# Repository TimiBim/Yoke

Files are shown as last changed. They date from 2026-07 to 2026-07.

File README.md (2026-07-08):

# Yoke



A sim racing steering wheel / yoke controller built around an STM32G491VE.

## Overview

Yoke is a wheel-side controller for a sim racing rig. It handles button and
encoder input, drives a color touch display, and communicates with the base
over CAN bus. Power and data arrive over a single hot-pluggable connector.

## Features

- **STM32G491VE** (LQFP100, Cortex-M4F @ 170 MHz)
- **FDCAN** link to the wheel base via TCAN332G transceiver
- **ILI9341** 320×240 SPI touch display
- **MCP23017** I²C expander for button matrix
- **Hot-plug safe** — MIC2544 current-limit controller and charge pump so the
  wheel can be connected while the rig is powered
- **ESD protection** on all external connections (ESD2CAN24DCKRQ1)
- **USB-C** for firmware flashing and debug

## Power Architecture

The base supplies a 5 V intermediate rail. An AP2114H-3.3 LDO generates the
local 3.3 V rail on the wheel, keeping the connector current low and avoiding
drop across the cable.

## License

- Hardware: CERN-OHL-S v2
- Firmware: MIT

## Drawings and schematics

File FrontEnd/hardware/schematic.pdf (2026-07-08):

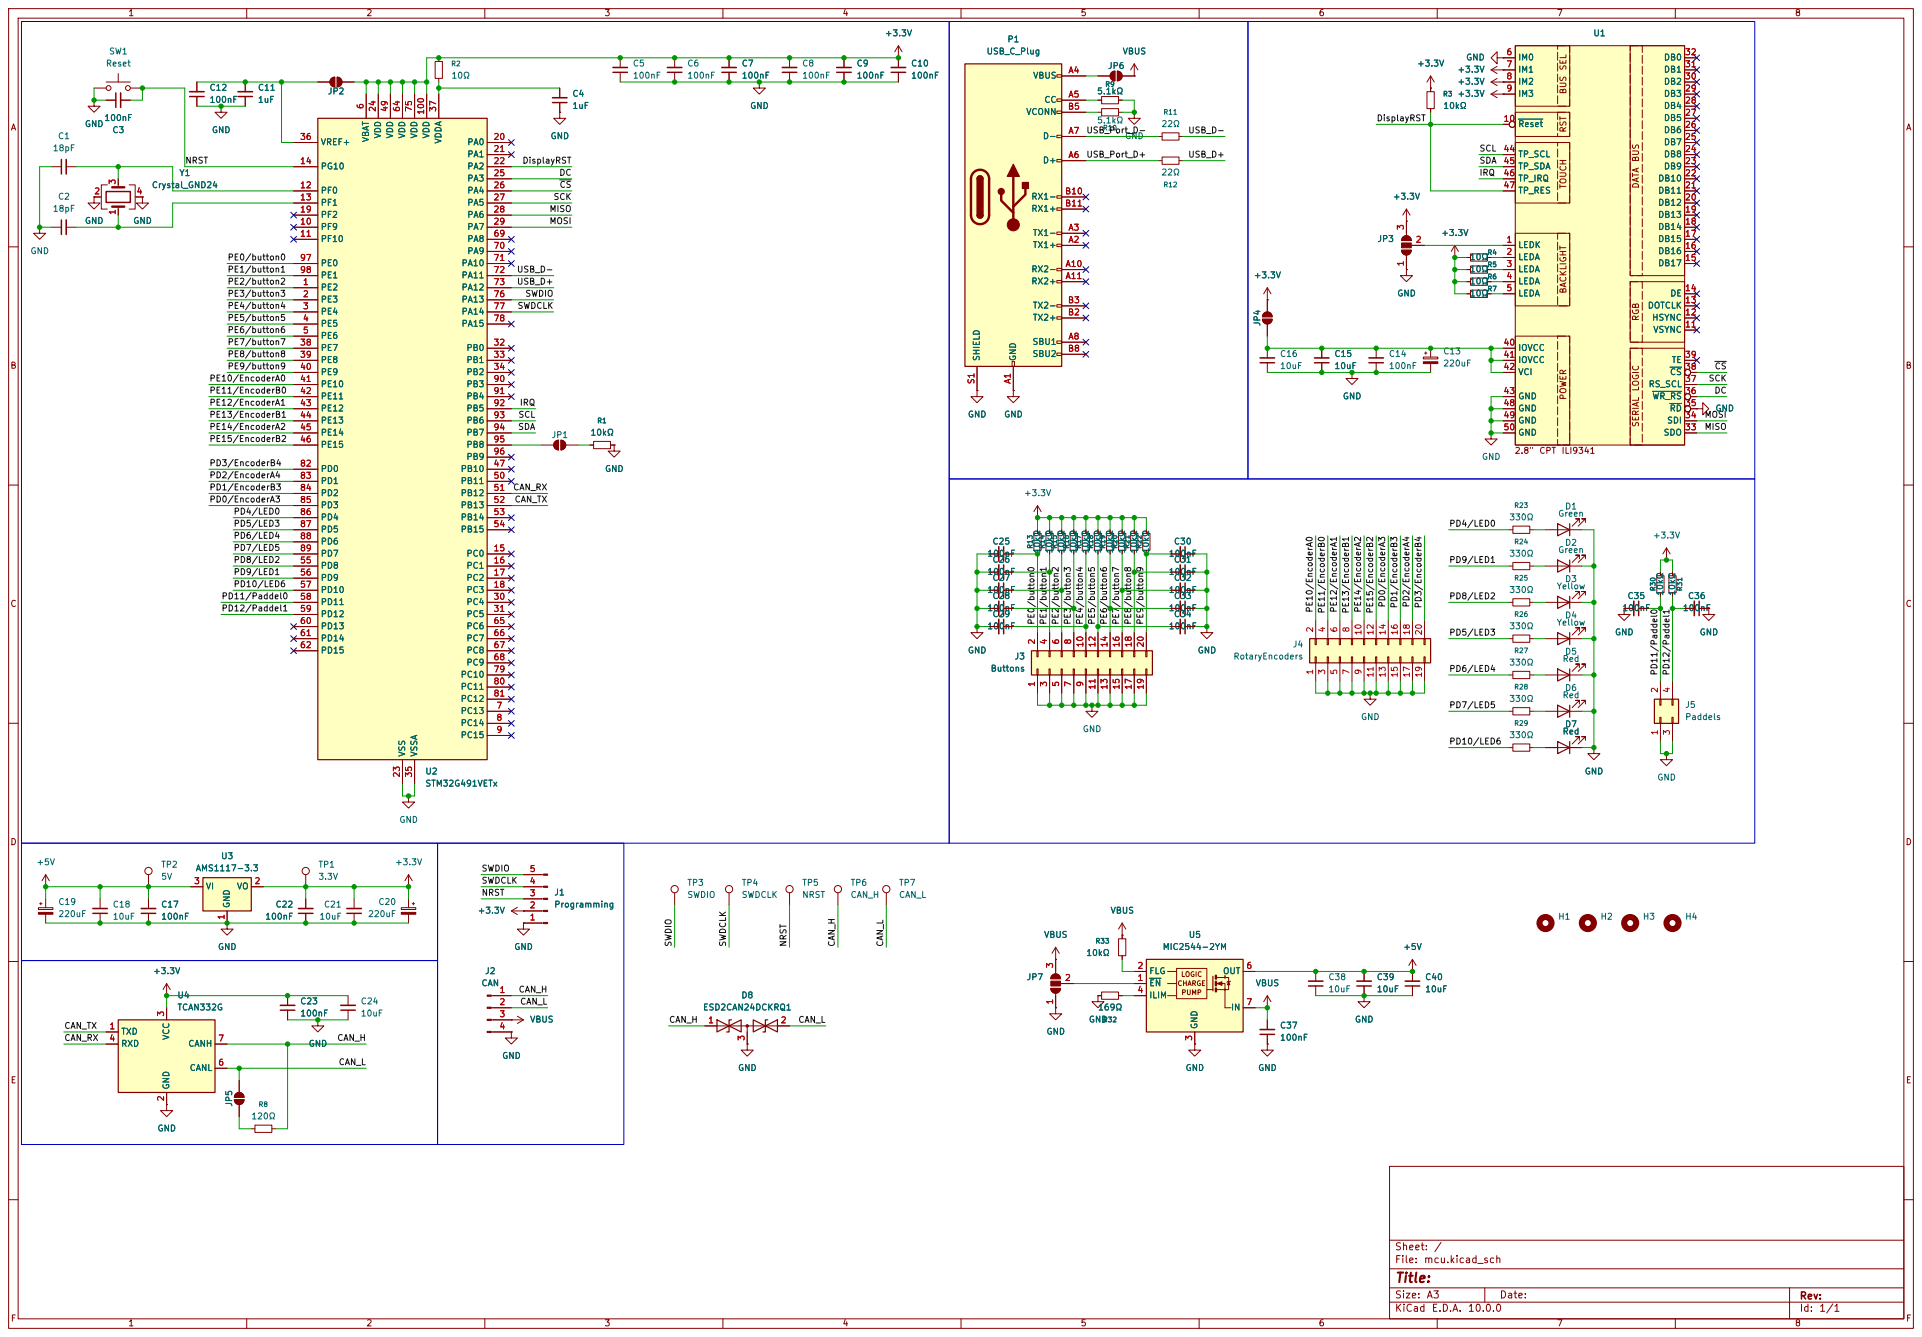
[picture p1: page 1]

VBUS | U1

MISO MOSI DisplayRST DC

LEDK 1

R4 10Ω | LEDA 3

3 RXD 4 CANL 6 CANH 7 JP5 GND

Size: A3 | Rev: | F Date:
KiCad E.D.A. 10.0.0 | Id: 1/1

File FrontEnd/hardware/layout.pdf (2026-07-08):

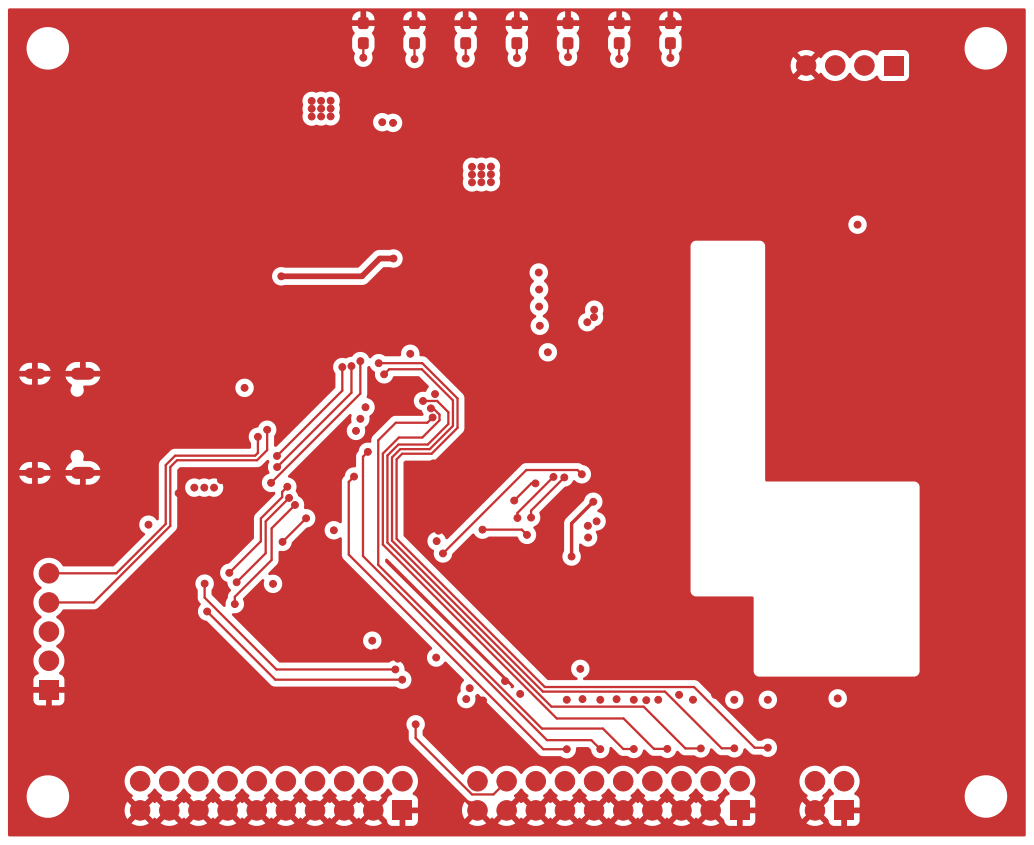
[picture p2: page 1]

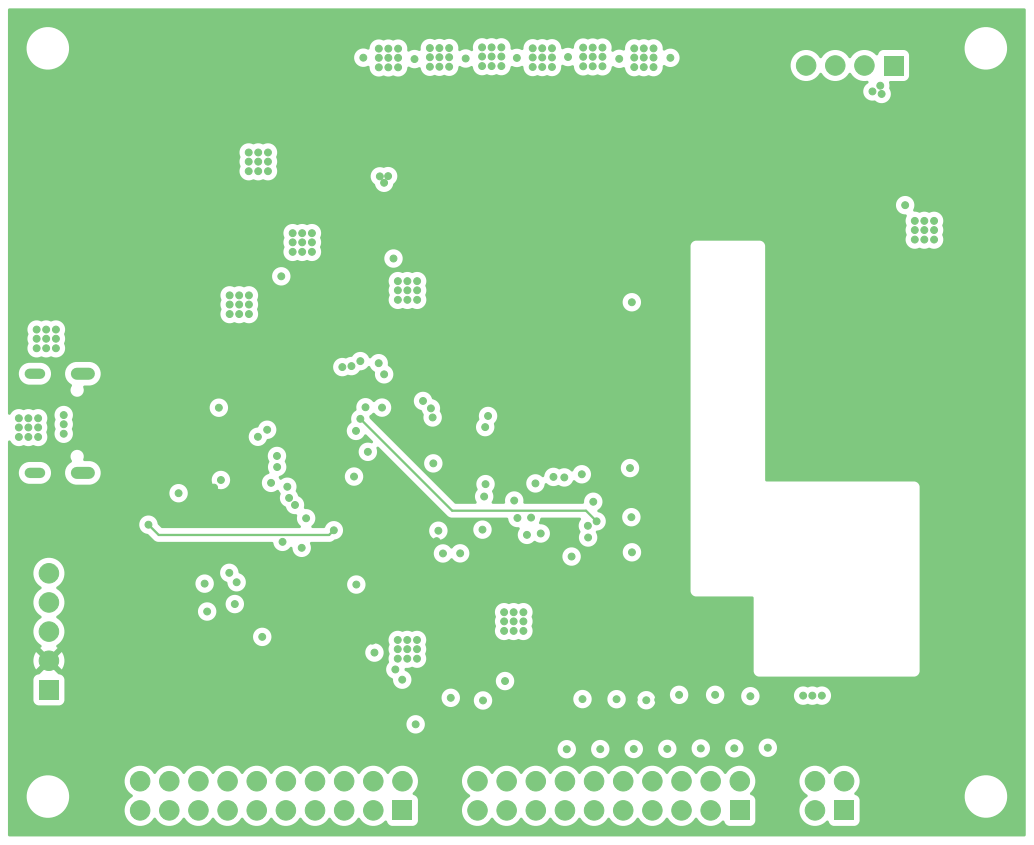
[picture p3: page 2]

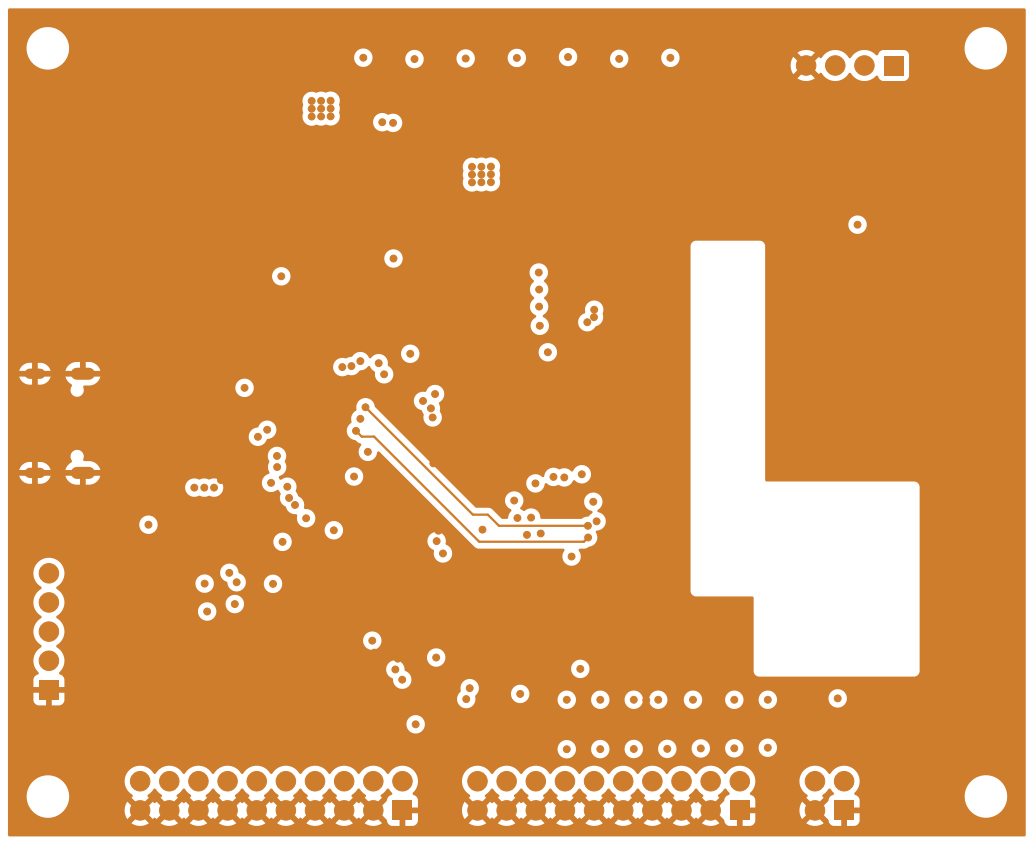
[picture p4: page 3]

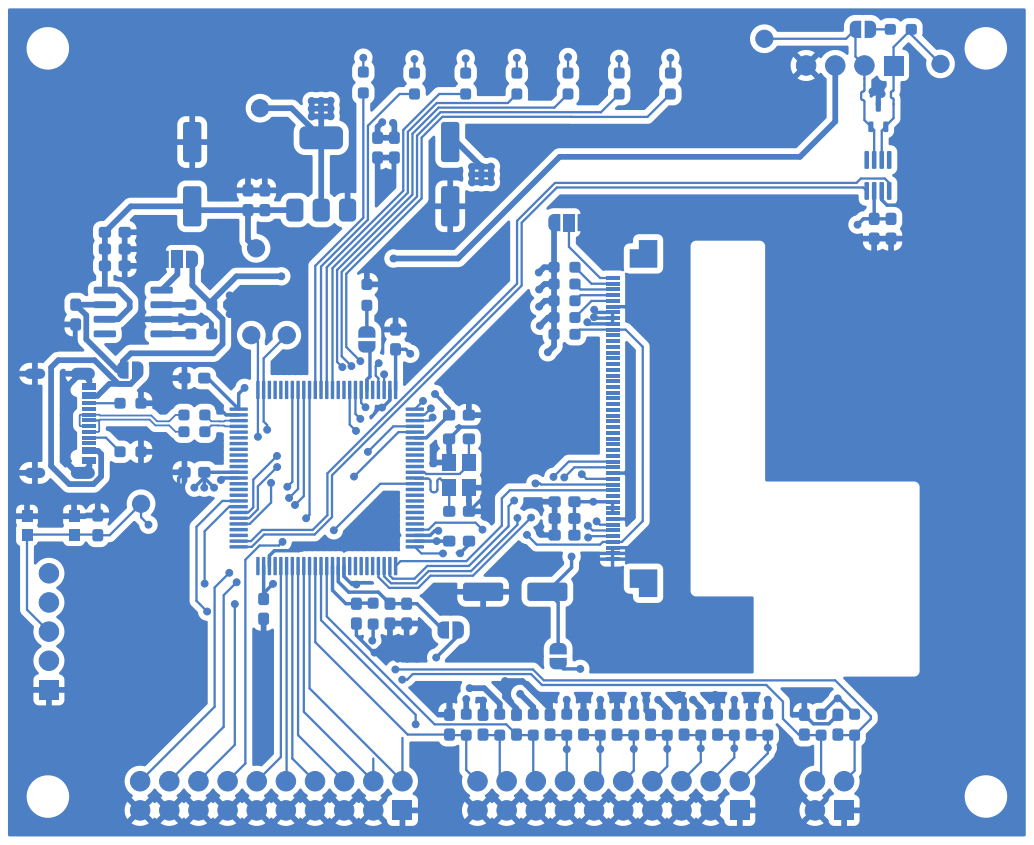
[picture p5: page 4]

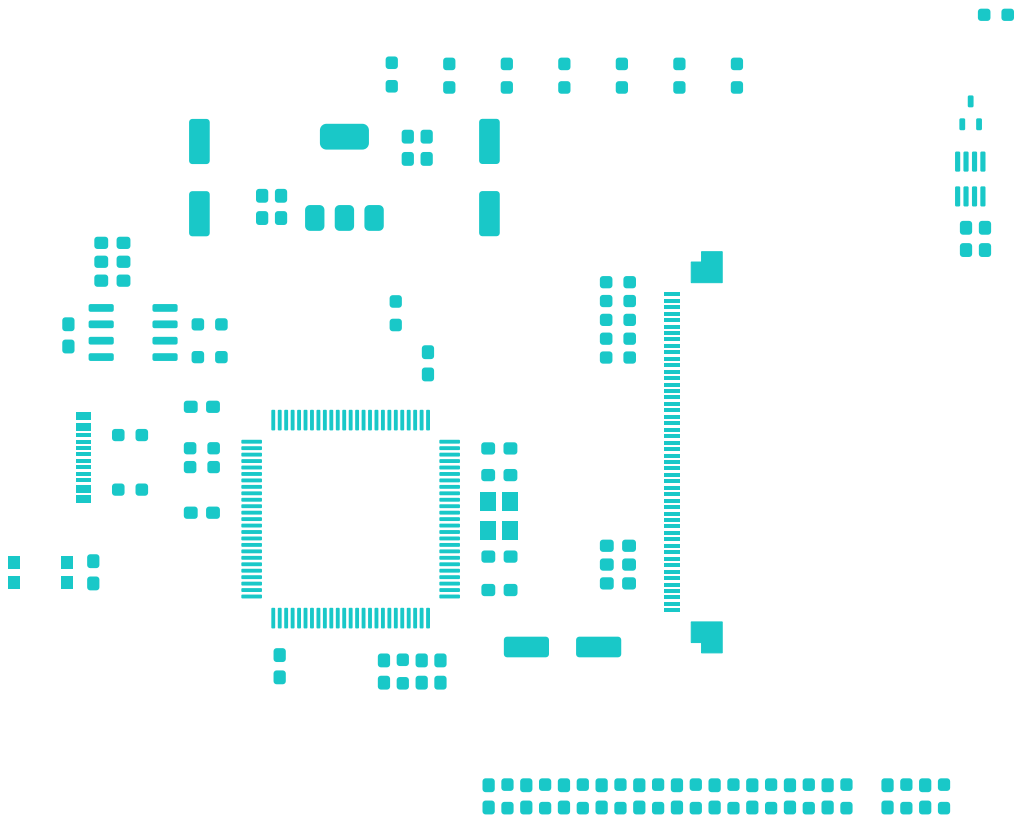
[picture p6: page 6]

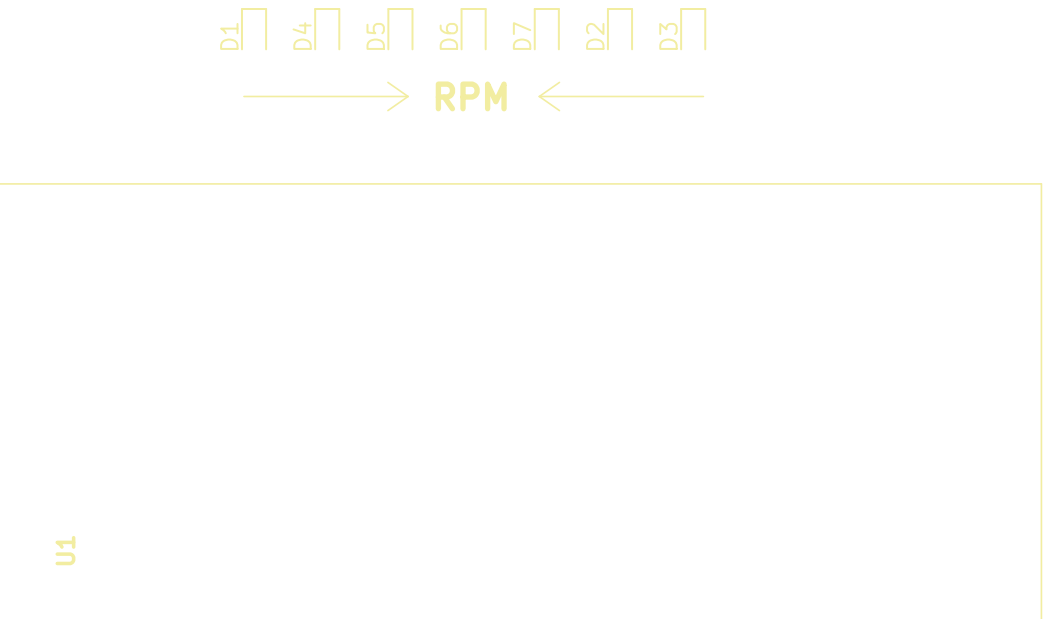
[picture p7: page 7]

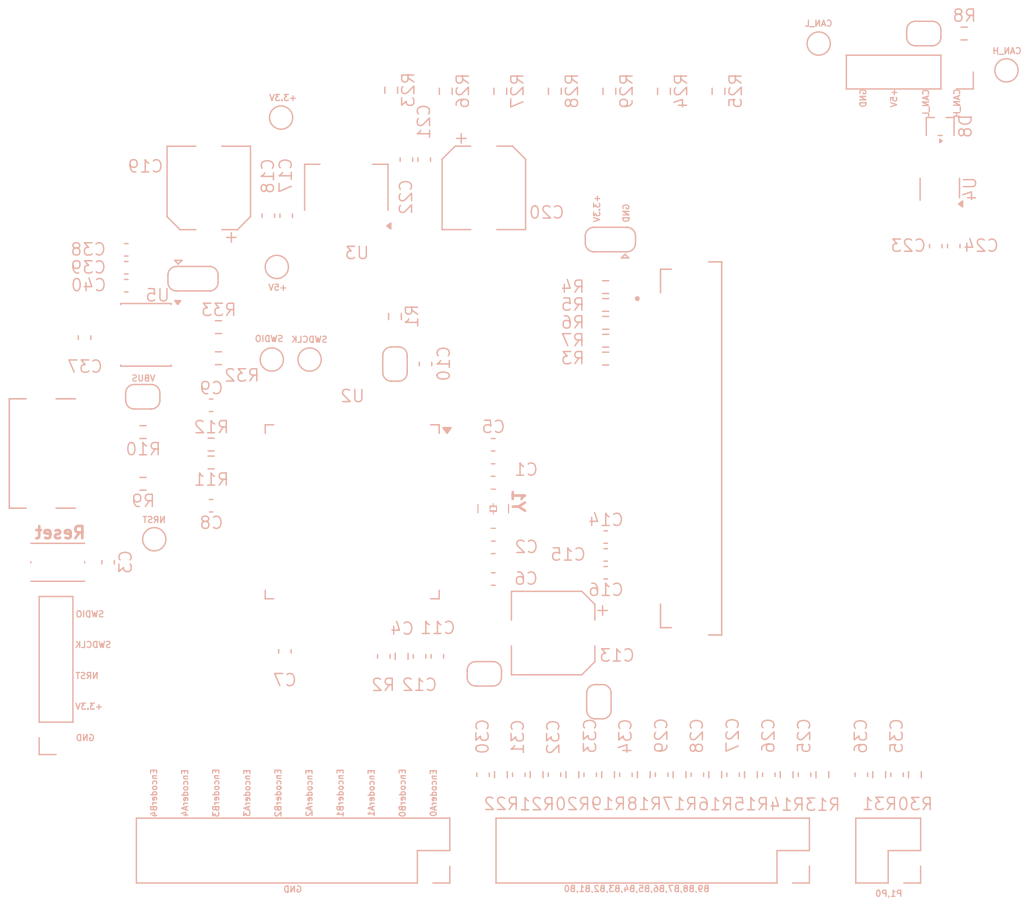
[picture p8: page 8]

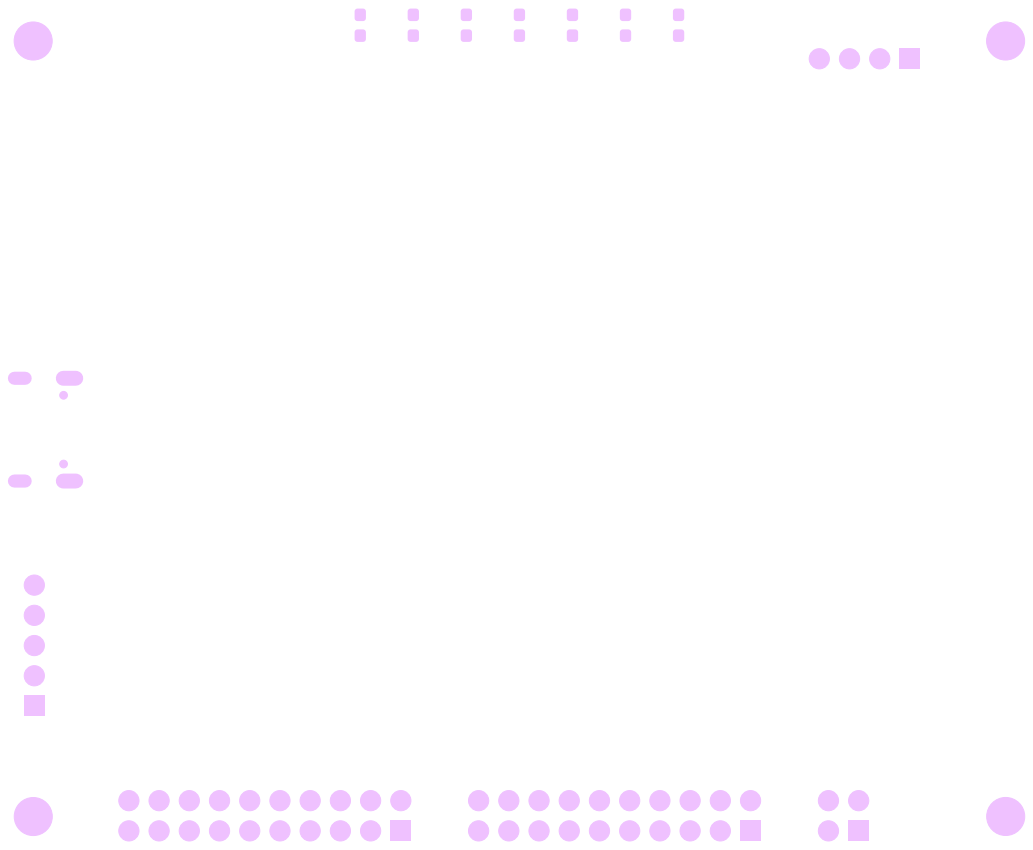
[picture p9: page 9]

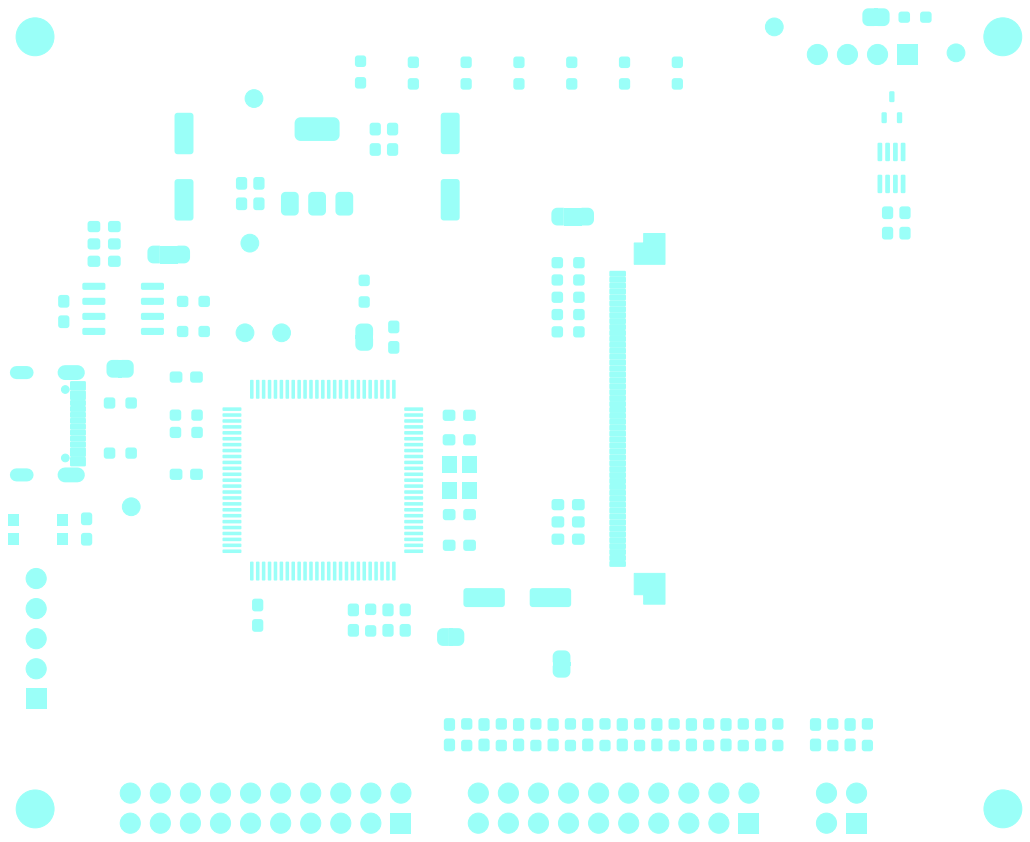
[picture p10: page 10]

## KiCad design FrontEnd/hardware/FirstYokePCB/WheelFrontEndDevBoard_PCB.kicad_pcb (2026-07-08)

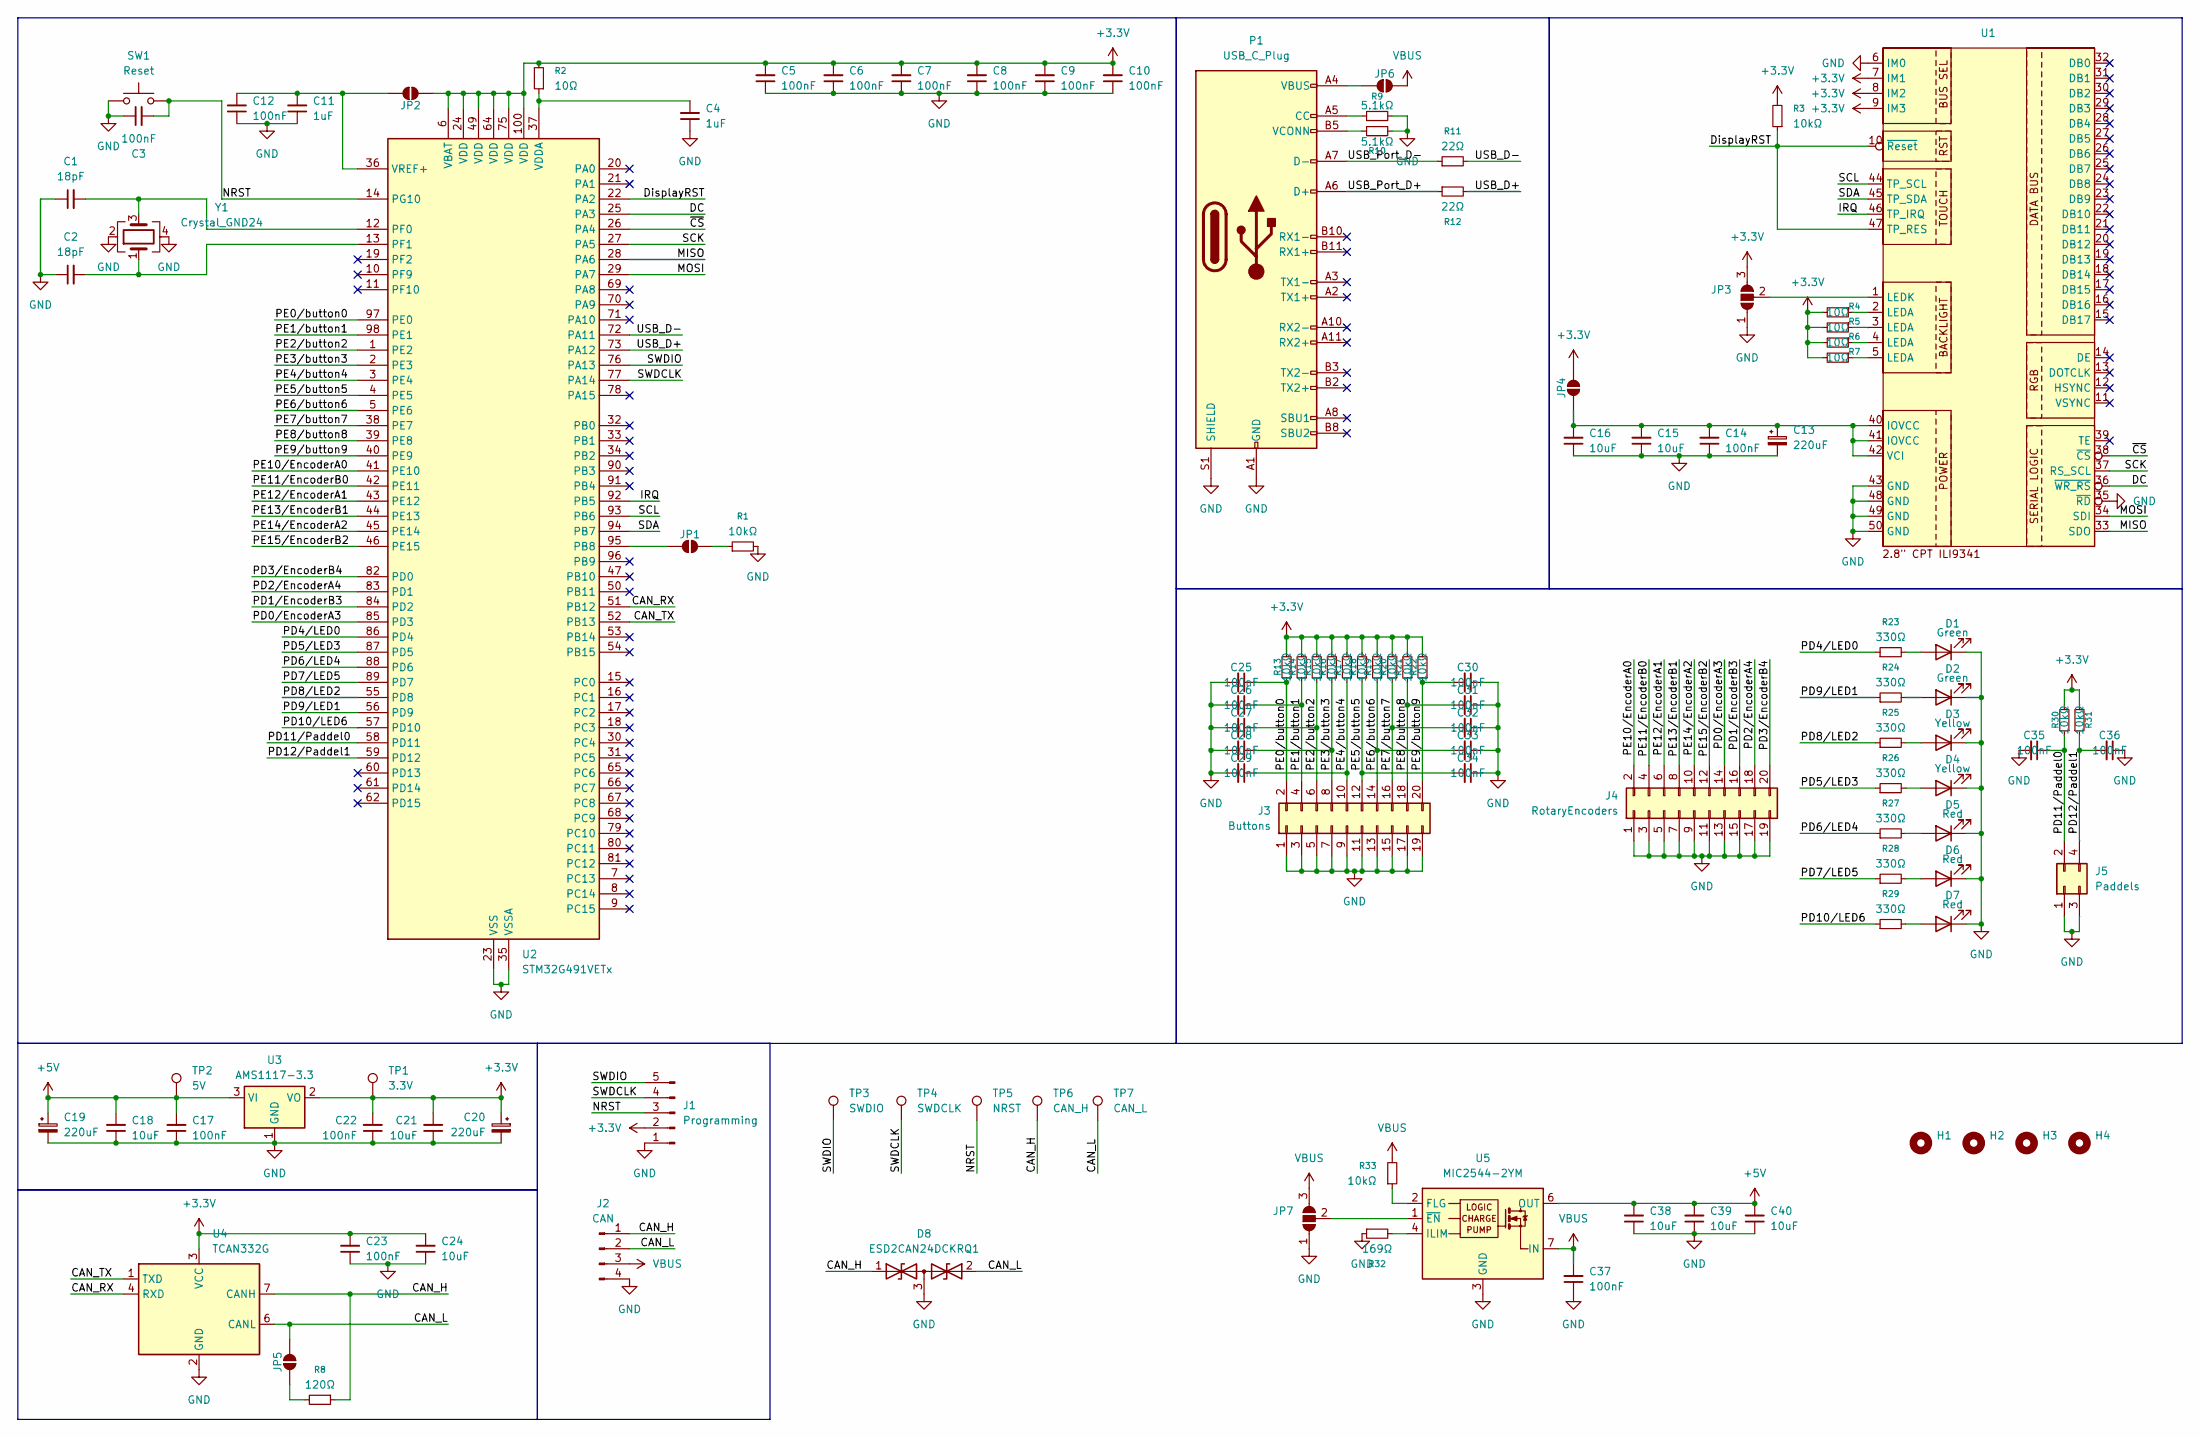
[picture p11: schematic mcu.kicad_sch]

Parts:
C1, C2: 18pF; C_0603_1608Metric_Pad1.08x0.95mm_HandSolder
C3, C5, C6, C7, C8, C9, C10, C12, C14, C17, C22, C23, C25, C26, C27, C28, C29, C30, C31, C32, C33, C34, C35, C36, C37: 100nF; C_0603_1608Metric_Pad1.08x0.95mm_HandSolder
C4, C11: 1uF; C_0603_1608Metric_Pad1.08x0.95mm_HandSolder
C13, C19, C20: 220uF; CP_Elec_6.3x5.3
C15, C16, C18, C21, C24, C38, C39, C40: 10uF; C_0603_1608Metric_Pad1.08x0.95mm_HandSolder
D1, D2: Green; LED_0603_1608Metric_Pad1.05x0.95mm_HandSolder
D3, D4: Yellow; LED_0603_1608Metric_Pad1.05x0.95mm_HandSolder
D5, D6, D7: Red; LED_0603_1608Metric_Pad1.05x0.95mm_HandSolder
D8: ESD2CAN24DCKRQ1; SOT-323_SC-70
H1, H2, H3, H4: MountingHole; MountingHole_3.2mm_M3
J1: Programming; PinHeader_1x05_P2.54mm_Vertical
J2: CAN; PinHeader_1x04_P2.54mm_Vertical
J3: Buttons; PinHeader_2x10_P2.54mm_Vertical
J4: RotaryEncoders; PinHeader_2x10_P2.54mm_Vertical
J5: Paddels; PinHeader_2x02_P2.54mm_Vertical
JP1, JP2, JP4, JP5, JP6: SolderJumper_2_Open; SolderJumper-2_P1.3mm_Open_RoundedPad1.0x1.5mm
JP3, JP7: SolderJumper_3_Open; SolderJumper-3_P1.3mm_Open_RoundedPad1.0x1.5mm
P1: USB_C_Plug; USB-C
R1, R3, R13, R14, R15, R16, R17, R18, R19, R20, R21, R22, R30, R31, R33: 10kΩ; R_0603_1608Metric_Pad0.98x0.95mm_HandSolder
R2, R4, R5, R6, R7: 10Ω; R_0603_1608Metric_Pad0.98x0.95mm_HandSolder
R8: 120Ω; R_0603_1608Metric_Pad0.98x0.95mm_HandSolder
R9, R10: 5.1kΩ; R_0603_1608Metric_Pad0.98x0.95mm_HandSolder
R11, R12: 22Ω; R_0603_1608Metric_Pad0.98x0.95mm_HandSolder
R23, R24, R25, R26, R27, R28, R29: 330Ω; R_0603_1608Metric_Pad0.98x0.95mm_HandSolder
R32: 169Ω; R_0603_1608Metric_Pad0.98x0.95mm_HandSolder
SW1: Reset; PTS815
TP1: 3.3V; TestPoint_Pad_D1.5mm
TP2: 5V; TestPoint_Pad_D1.5mm
TP3: SWDIO; TestPoint_Pad_D1.5mm
TP4: SWDCLK; TestPoint_Pad_D1.5mm
TP5: NRST; TestPoint_Pad_D1.5mm
TP6: CAN_H; TestPoint_Pad_D1.5mm
TP7: CAN_L; TestPoint_Pad_D1.5mm
U1: Adafruit 2.8_ capacitiveTouchScreen
U2: STM32G491VETx; LQFP-100_14x14mm_P0.5mm
U3: AMS1117-3.3; SOT-223-3_TabPin2
U4: TCAN332G; SOT-23-8_Handsoldering
U5: MIC2544-2YM; SOIC-8_3.9x4.9mm_P1.27mm
Y1: Crystal_GND24; ABM8G

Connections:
+3.3V: C5.2, C6.2, C7.2, C8.2, C9.2, C10.2, C20.1, C21.2, C22.2, C23.2, C24.2, J1.2, JP2.1 (A), JP3.3 (B), JP4.2 (B), R2.2, R3.2, R4.2, R5.2, R6.2, R7.2, R13.2, R14.2, R15.2, R16.2, R17.2, R18.2, R19.2, R20.2, R21.2, R22.2, R30.2, R31.2, TP1.1 (1_1), U1.7 (IM1), U1.8 (IM2), U1.9 (IM3), U2.6 (VBAT), U2.24 (VDD), U2.49 (VDD), U2.64 (VDD), U2.75 (VDD), U2.100 (VDD), U3.2 (VO), U4.3 (VCC)
+5V: C17.2, C18.2, C19.1, C38.2, C39.2, C40.2, TP2.1 (1_1), U3.3 (VI), U5.6 (OUT), U5.8 (OUT)
/MCU/CAN_H: D8.1 (A1), J2.1, R8.1, TP6.1 (1_1), U4.7 (CANH)
/MCU/CAN_L: D8.2 (A2), J2.2, JP5.2 (B), TP7.1 (1_1), U4.6 (CANL)
/MCU/CAN_RX: U2.51 (PB12), U4.4 (RXD)
/MCU/CAN_TX: U2.52 (PB13), U4.1 (TXD)
/MCU/DC: U1.36 (~WR_RS), U2.25 (PA3)
/MCU/DisplayRST: R3.1, U1.10 (~Reset), U1.47 (TP_RES), U2.22 (PA2)
/MCU/IRQ: U1.46 (TP_IRQ), U2.92 (PB5)
/MCU/MISO: U1.33 (SDO), U2.28 (PA6)
/MCU/MOSI: U1.34 (SDI), U2.29 (PA7)
/MCU/NRST: C3.2, J1.3, SW1.2, TP5.1 (1_1), U2.14 (PG10)
/MCU/PD0/EncoderA3: J4.14, U2.85 (PD3)
/MCU/PD1/EncoderB3: J4.16, U2.84 (PD2)
/MCU/PD2/EncoderA4: J4.18, U2.83 (PD1)
/MCU/PD3/EncoderB4: J4.20, U2.82 (PD0)
/MCU/PD4/LED0: R23.1, U2.86 (PD4)
/MCU/PD5/LED3: R26.1, U2.87 (PD5)
/MCU/PD6/LED4: R27.1, U2.88 (PD6)
/MCU/PD7/LED5: R28.1, U2.89 (PD7)
/MCU/PD8/LED2: R25.1, U2.55 (PD8)
/MCU/PD9/LED1: R24.1, U2.56 (PD9)
/MCU/PD10/LED6: R29.1, U2.57 (PD10)
/MCU/PD11/Paddel0: C35.1, J5.2, R30.1, U2.58 (PD11)
/MCU/PD12/Paddel1: C36.2, J5.4, R31.1, U2.59 (PD12)
/MCU/PE0/button0: C25.1, J3.2, R13.1, U2.97 (PE0)
/MCU/PE1/button1: C26.1, J3.4, R14.1, U2.98 (PE1)
/MCU/PE2/button2: C27.1, J3.6, R15.1, U2.1 (PE2)
/MCU/PE3/button3: C28.1, J3.8, R16.1, U2.2 (PE3)
/MCU/PE4/button4: C29.1, J3.10, R17.1, U2.3 (PE4)
/MCU/PE5/button5: C34.2, J3.12, R18.1, U2.4 (PE5)
/MCU/PE6/button6: C33.2, J3.14, R19.1, U2.5 (PE6)
/MCU/PE7/button7: C32.2, J3.16, R20.1, U2.38 (PE7)
/MCU/PE8/button8: C31.2, J3.18, R21.1, U2.39 (PE8)
/MCU/PE9/button9: C30.2, J3.20, R22.1, U2.40 (PE9)
/MCU/PE10/EncoderA0: J4.2, U2.41 (PE10)
/MCU/PE11/EncoderB0: J4.4, U2.42 (PE11)
/MCU/PE12/EncoderA1: J4.6, U2.43 (PE12)
/MCU/PE13/EncoderB1: J4.8, U2.44 (PE13)
/MCU/PE14/EncoderA2: J4.10, U2.45 (PE14)
/MCU/PE15/EncoderB2: J4.12, U2.46 (PE15)
/MCU/SCK: U1.37 (RS_SCL), U2.27 (PA5)
/MCU/SCL: U1.44 (TP_SCL), U2.93 (PB6)
/MCU/SDA: U1.45 (TP_SDA), U2.94 (PB7)
/MCU/SWDCLK: J1.4, TP4.1 (1_1), U2.77 (PA14)
/MCU/SWDIO: J1.5, TP3.1 (1_1), U2.76 (PA13)
/MCU/USB_D+: R12.2, U2.73 (PA12)
/MCU/USB_D-: R11.2, U2.72 (PA11)
/MCU/USB_Port_D+: P1.A6 (D+), R12.1
/MCU/USB_Port_D-: P1.A7 (D-), R11.1
/MCU/~CS: U1.38 (~CS), U2.26 (PA4)
GND: C1.1, C2.1, C3.1, C4.1, C5.1, C6.1, C7.1, C8.1, C9.1, C10.1, C11.1, C12.1, C13.2, C14.1, C15.1, C16.1, C17.1, C18.1, C19.2, C20.2, C21.1, C22.1, C23.1, C24.1, C25.2, C26.2, C27.2, C28.2, C29.2, C30.1, C31.1, C32.1, C33.1, C34.1, C35.2, C36.1, C37.1, C38.1, C39.1, C40.1, D1.1 (K), D2.1 (K), D3.1 (K), D4.1 (K), D5.1 (K), D6.1 (K), D7.1 (K), D8.3 (common), J1.1, J2.4, J3.1, J3.3, J3.5, J3.7, J3.9, J3.11, J3.13, J3.15, J3.17, J3.19, J4.1, J4.3, J4.5, J4.7, J4.9, J4.11, J4.13, J4.15, J4.17, J4.19, J5.1, J5.3, JP3.1 (A), JP7.1 (A), P1.A1 (GND), P1.A12 (GND), P1.B1 (GND), P1.B12 (GND), P1.S1 (SHIELD), R1.2, R9.2, R10.2, R32.1, SW1.1, U1.6 (IM0), U1.35 (~RD), U1.43 (GND), U1.48 (GND), U1.49 (GND), U1.50 (GND), U2.23 (VSS), U2.35 (VSSA), U2.48 (VSS), U2.63 (VSS), U2.74 (VSS), U2.99 (VSS), U3.1 (GND), U4.2 (GND), U5.3 (GND), Y1.2, Y1.4
unnamed: D1.2 (A), R23.2
unnamed: D2.2 (A), R24.2
unnamed: D3.2 (A), R25.2
unnamed: D4.2 (A), R26.2
unnamed: D5.2 (A), R27.2
unnamed: D6.2 (A), R28.2
unnamed: D7.2 (A), R29.2
unnamed: JP1.1 (A), U2.95 (PB8)
unnamed: JP1.2 (B), R1.1
unnamed: C11.2, C12.2, JP2.2 (B), U2.36 (VREF+)
unnamed: JP3.2 (C), U1.1 (LEDK)
unnamed: C13.1, C14.2, C15.2, C16.2, JP4.1 (A), U1.40 (IOVCC), U1.41 (IOVCC), U1.42 (VCI)
unnamed: JP5.1 (A), R8.2
unnamed: JP6.1 (A), P1.A4 (VBUS), P1.A9 (VBUS), P1.B4 (VBUS), P1.B9 (VBUS)
unnamed: JP7.2 (C), U5.1 (~EN)
unnamed: P1.A5 (CC), R9.1
unnamed: P1.B5 (VCONN), R10.1
unnamed: R4.1, U1.2 (LEDA)
unnamed: R5.1, U1.3 (LEDA)
unnamed: R6.1, U1.4 (LEDA)
unnamed: R7.1, U1.5 (LEDA)
unnamed: C1.2, U2.12 (PF0), Y1.3
unnamed: C2.2, U2.13 (PF1), Y1.1
unnamed: C4.2, R2.1, U2.37 (VDDA)
unnamed: R33.1, U5.2 (FLG)
unnamed: R32.2, U5.4 (ILIM)
VBUS: C37.2, J2.3, JP6.2 (B), JP7.3 (B), R33.2, U5.7 (IN)

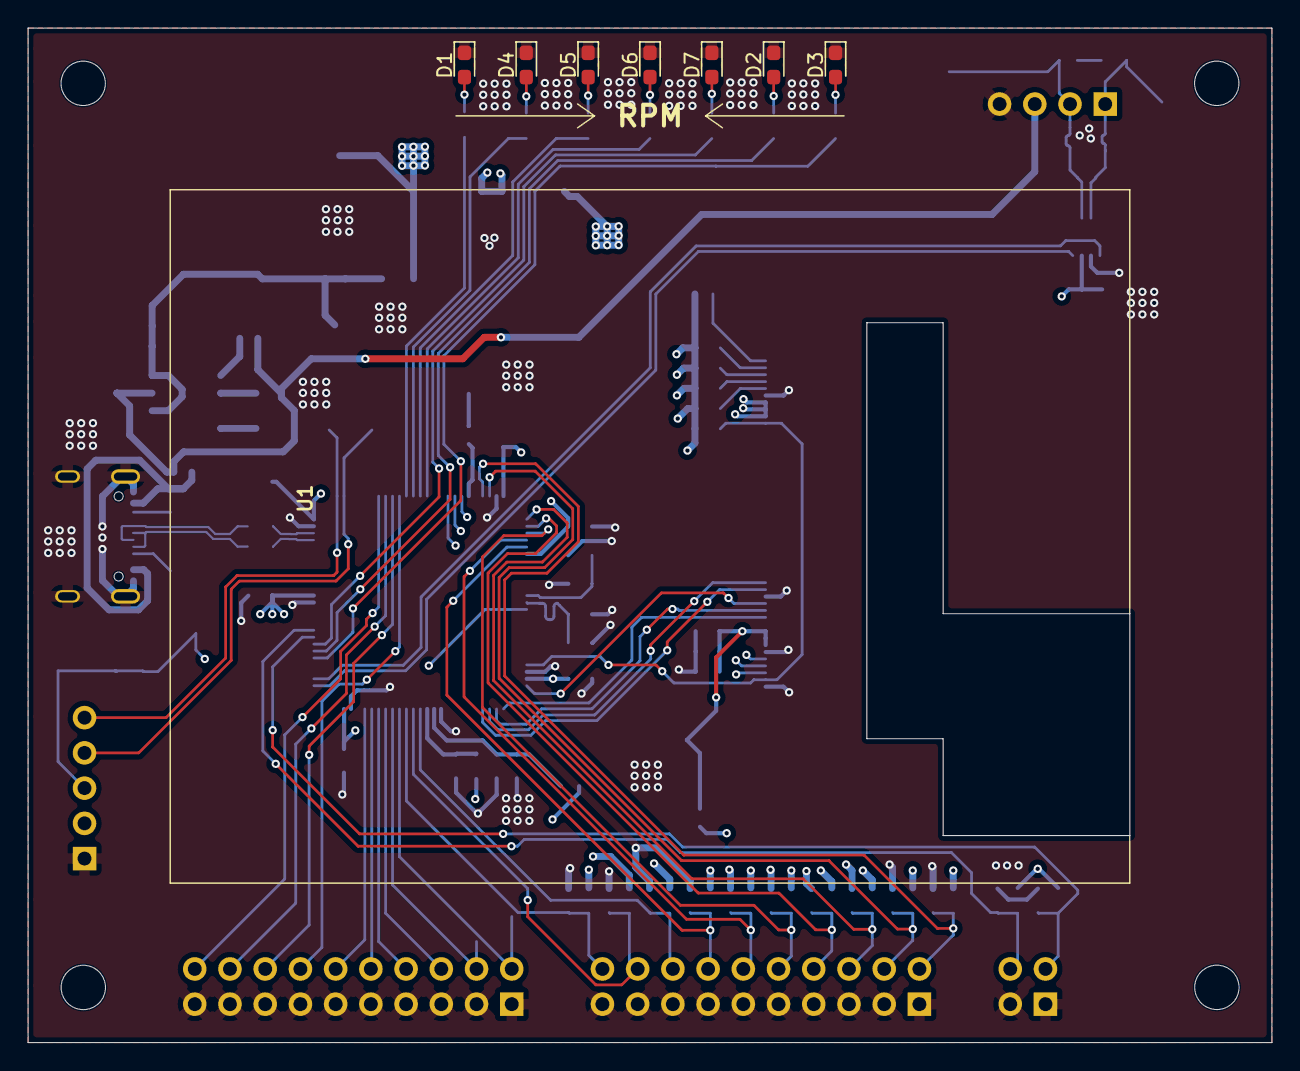
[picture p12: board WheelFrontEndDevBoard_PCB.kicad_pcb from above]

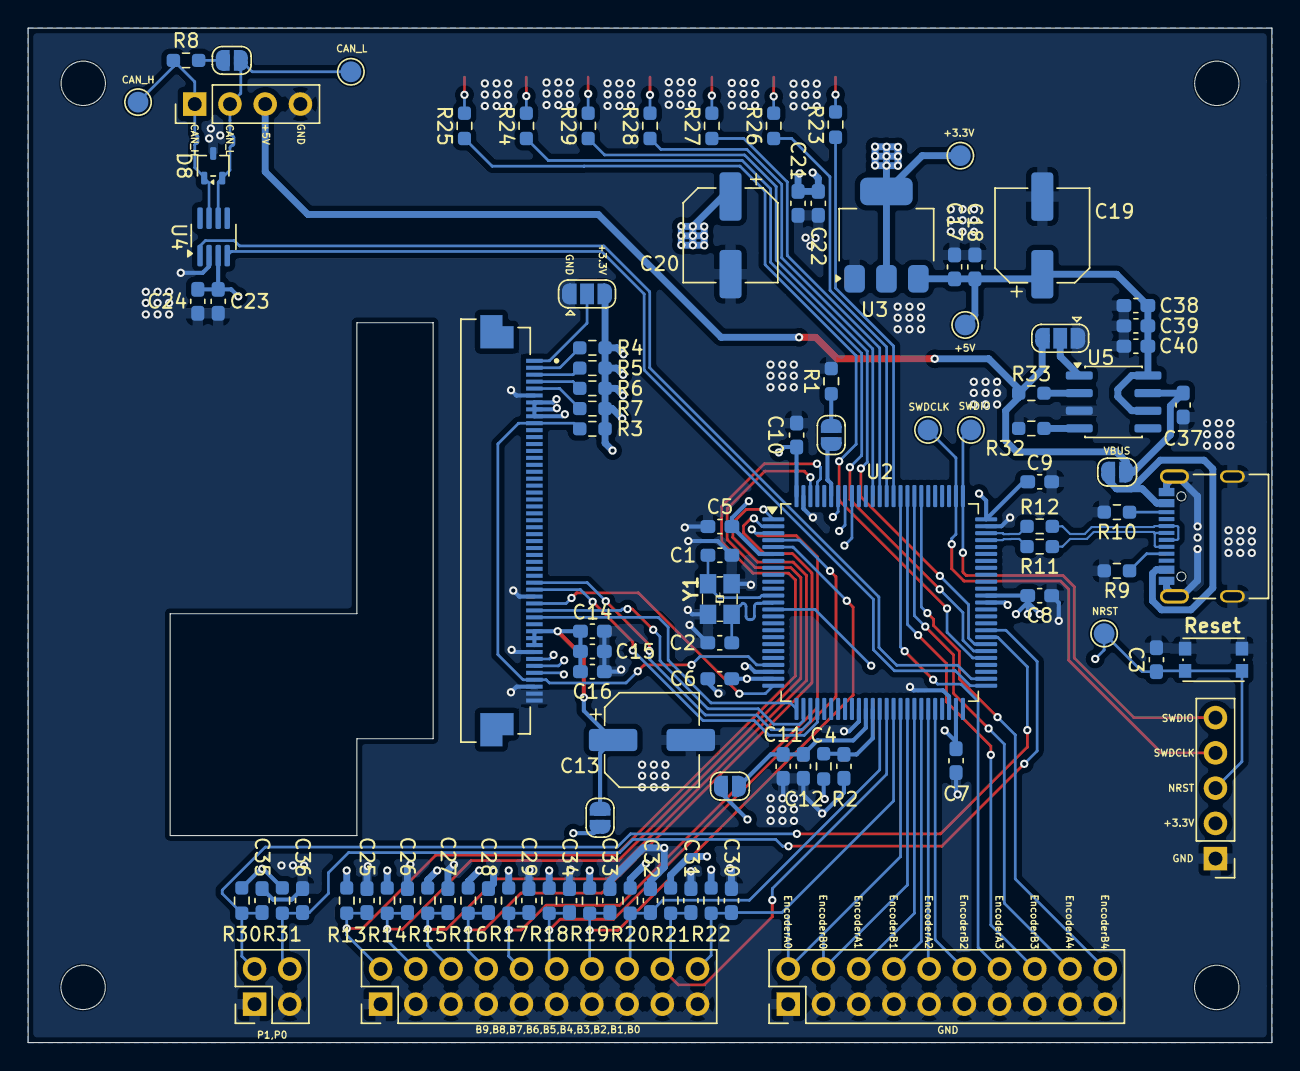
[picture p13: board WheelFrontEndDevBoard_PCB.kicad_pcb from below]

Board: 4 copper layers, 89.7 x 73.2 mm, 112 parts (100 on the bottom side), 79 nets.

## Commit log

2026-07-08 Finished PCB (finished layout)
    [WheelFrontEndDevBoard_PCB.kicad_pcb, mcu.kicad_sch]
2026-07-08 Enhance README with project details and features
    Expanded the README.md to include detailed project overview, features, power architecture, and licensing information.
2026-07-08 Added production data, BOM and pdfs for the scheamtic and layout
    [WheelFrontEndDevBoard_PCB-B_Cu.gbr, WheelFrontEndDevBoard_PCB-B_Mask.gbr, WheelFrontEndDevBoard_PCB-B_Paste.gbr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]
2026-07-08 Update README to remove obsolete information
    Removed cable break detection and firmware license conflicts from README.
